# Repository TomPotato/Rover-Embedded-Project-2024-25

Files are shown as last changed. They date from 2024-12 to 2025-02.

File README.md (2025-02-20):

<h1 align="center">The Mars Rover: WALL-E</h1>

<p>With this project we aim to get a better understanding of what skills developing a Mars Rover takes.</p>
<p><i>"How does a Rover really work?","What actions or characteristics define a machine as a Rover?","How can we transmit and receive data from the Rover?"</i></p>
<p>While it would be challenging to build a full functioning Mars Rover in a limited timeframe, understanding how they work and the challenges engineers face, can give us a greater appreciation for the level of innovation and precision that goes into their development.</p>

<h3 align="center">The finished Product</h3>

<p float="left" align="center">
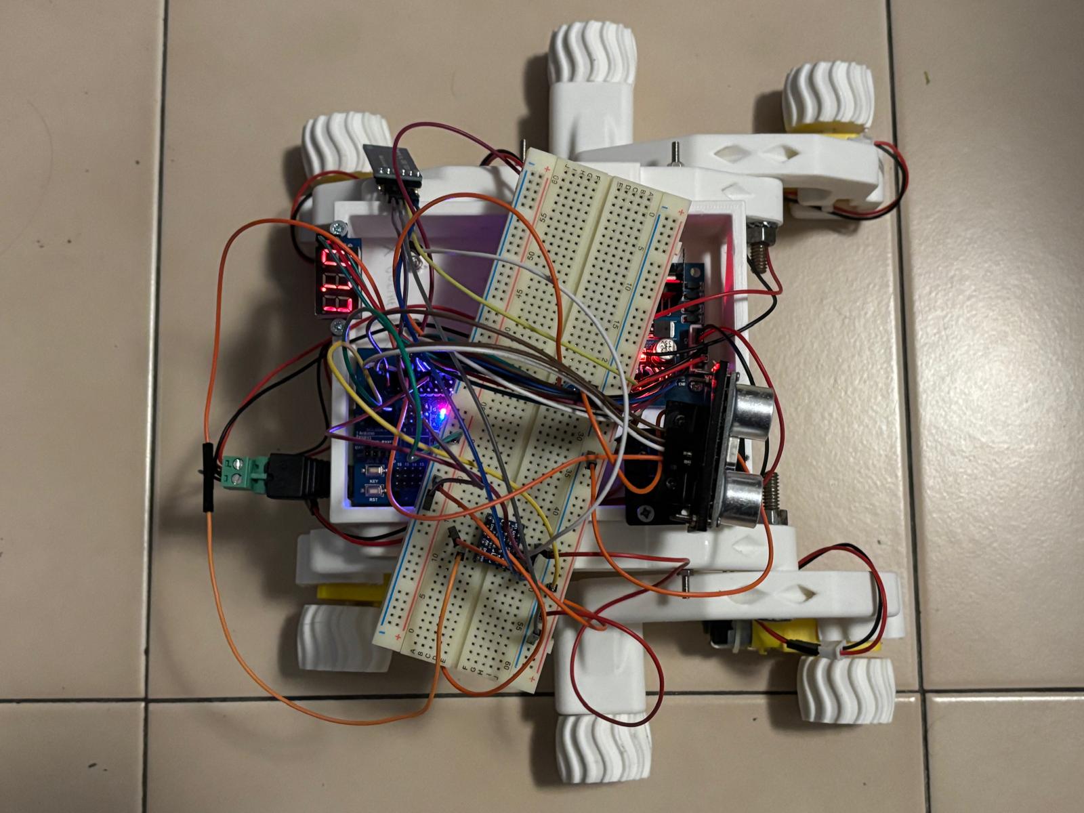
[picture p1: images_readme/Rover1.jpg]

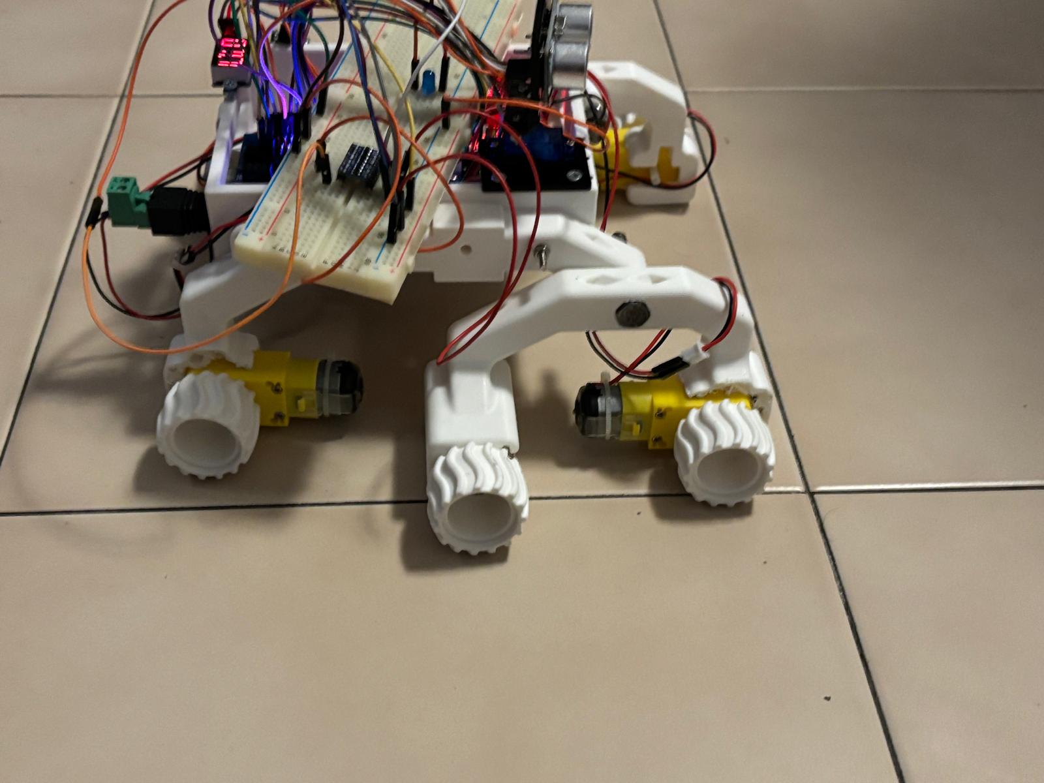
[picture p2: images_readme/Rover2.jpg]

</p>

<br>

<p float="left" align="center">
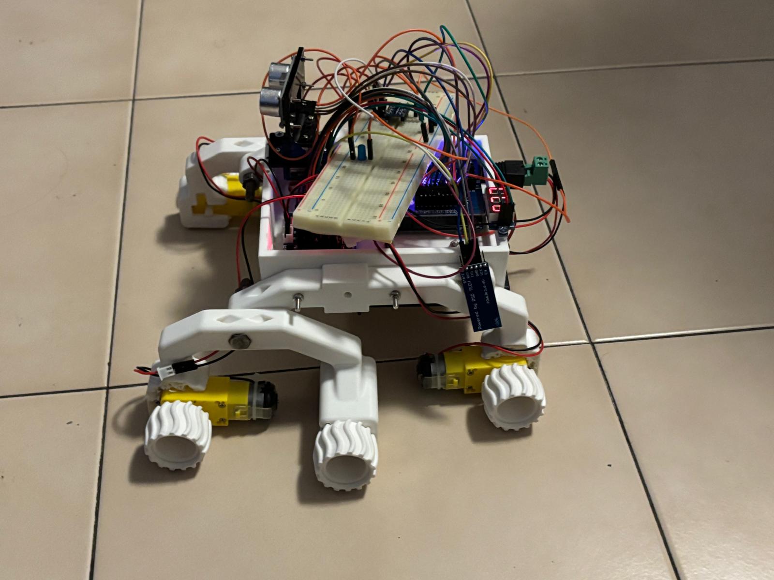
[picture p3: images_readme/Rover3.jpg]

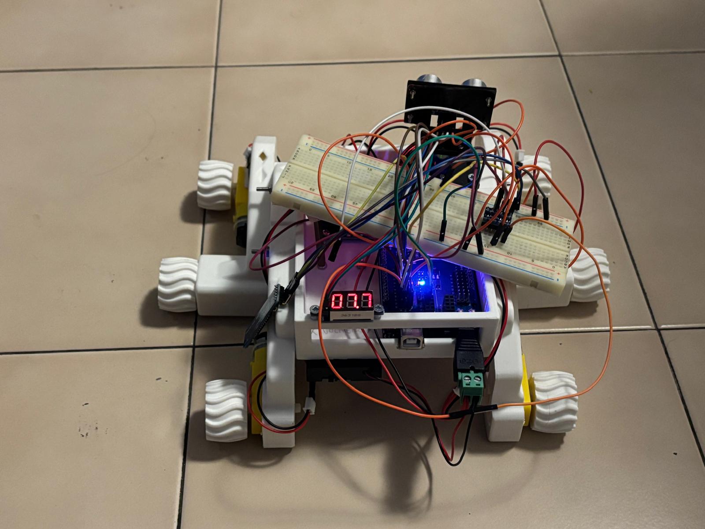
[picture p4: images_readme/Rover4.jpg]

</p>

<h2 align="center">Link to the Youtube video</h2>

<br>
<p>Here you'll find the link to the video of the project: <a href = "https://www.youtube.com/watch?v=d_bhMyztT9k">https://www.youtube.com/watch?v=d_bhMyztT9k</a></p>
<br>

<h2 align="center">Components</h2>

<h3 align="center">Physical Components Used</h3>

<ul>
    <li>a few (a lot) 3d printable components</li>
    <li>4x mini servomotors of 3v outtage</li>
    <li>27x Jumpers Arduino</li>
    <li>1x Micro Servo motor SG90</li>
    <li>1x Arduino compatible Voltmeter</li>
    <li>1x Arduino OSOYOO UNO Board</li>
    <li>1x Arduino ESP8266 Shield for Arduino</li>
    <li>1x Buzzer compatible with Arduino</li>
    <li>1x Module Driver Motors OSOYOO Model X</li>
    <li>1x Bluetooth sensor Arduino compatible HC-05</li>
    <li>1x Ultrasonic sensor HC-SR04</li>
    <li>nx Various screws and knobs to model the Body of the Rover</li>
    <li>1x BatteryPack</li>
        <ul>
        <li>2x Rechargable Batteries of 3.7V, ~3.000 mA</li>
        <li>1x Batteries Charge Station</li>
        </ul>
    <li>1x Texas Instruments MSP432P401R</li>
    <li>1x Texas Instruments BoosterPack MKII</li>
    <li>1x Breadboard</li>
    <li>1x Logic level converter</li>
    <li>1x LED</li>
    <li>1x PC/LAPTOP</li>
</ul>

<h3 align="center">Software Used</h3>

<ul>
    <li>Visual Studio Code</li>
    <li>Arduino IDE</li>
    <li>Energia IDE</li>
    <li>Putty Serial Communication App</li>
    <li>Windows CMD/Powershell</li>
</ul>

<h3 align="center">Programming Languages used</h3>

<ul>
    <li>C/C++</li>
    <li>Python</li>
</ul>

<h3 align="center">Libraries used</h3>

<ul>
    <li>Python library:serial</li>
    <li>Arduino library: SoftwareSerial.h , Servo.h</li>
</ul>

<h2 align="center">Project Layout</h2>

<pre>
<code>
ROVER WALL-E
│
├── README.md
├── LICENSE (MIT defined)
├── rover_exoscheleton               # stl used for the exoskeleton of the rover
├── images_readme                   
│   └──images                        # images used inside the readme
├── images_schematics               
│  └──images                         # schematics of the Arduino jumpers connections in the Rover
├── videos                           # snippets of the pitch video
├── Presentation                     # presentation of the project
└── Our Code
    ├── ArduinoUNO                   # Arduino side code
    │   ├── ComponentsCode           # Components template code with testing before implementation
    │   └── RoverFinalSketch         # Final sketch to be burned into the Rover
    ├── MSP43P401R                   # Texas side code
    └── SideCode                     # Side code to make the BT module connect to the pc 
</code>
</pre>

<h2 align="center">How to Reproduce the Project</h2>

<h3 align="center">Goals</h3>

<ul>
    <li>Sending commands from MSP432 (with attached a BoosterPack) to arduino via bluetooth to control the rover </li>
    <li>Commands that can be Issued:</li>
    <ul>
        <li>F(Forward)</li>
        <li>B(Backward)</li>
        <li>L(Left)</li>
        <li>R(Right)</li>
        <li>P(rovers' led on)</li>
        <li>W(rovers' led off)</li>      
    </ul>
    <li>Sending rovers' led status and ultrasonic data from arduino to the pc/laptop</li>
    <li>The multicolor LED integrated into the BoosterPack operates in accordance with control commands (e.g., LED ON/OFF) transmitted by the Arduino.</li>
</ul>

<h3 align="center">Steps</h3>
<ol>
    <i>After you printed the Rover Components and built its exoscheleton as the image shown below</i>
    <p>
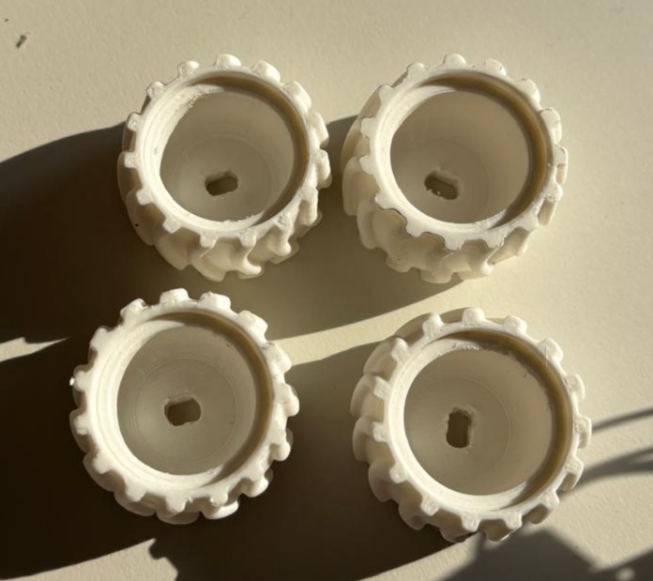
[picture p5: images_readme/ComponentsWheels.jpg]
    
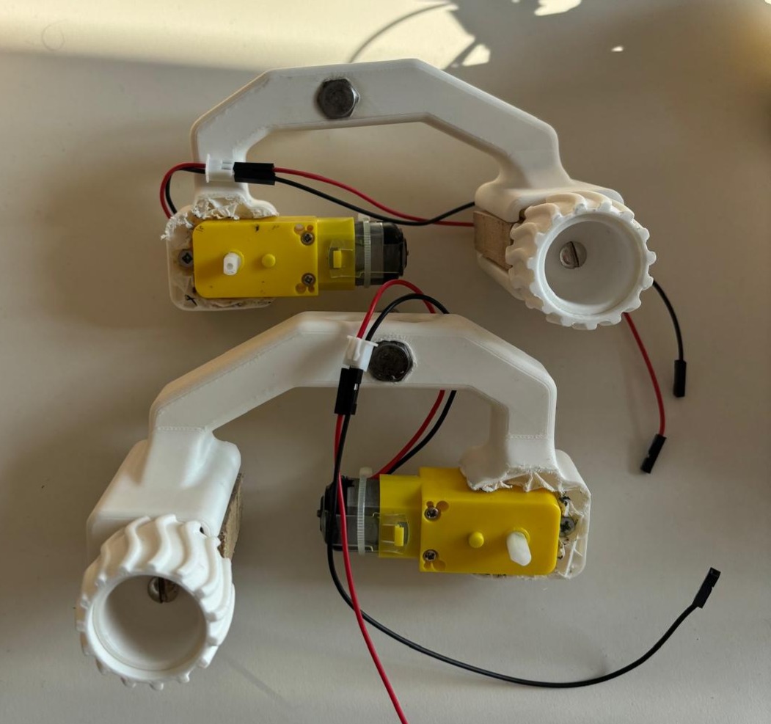
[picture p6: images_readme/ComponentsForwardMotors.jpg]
    
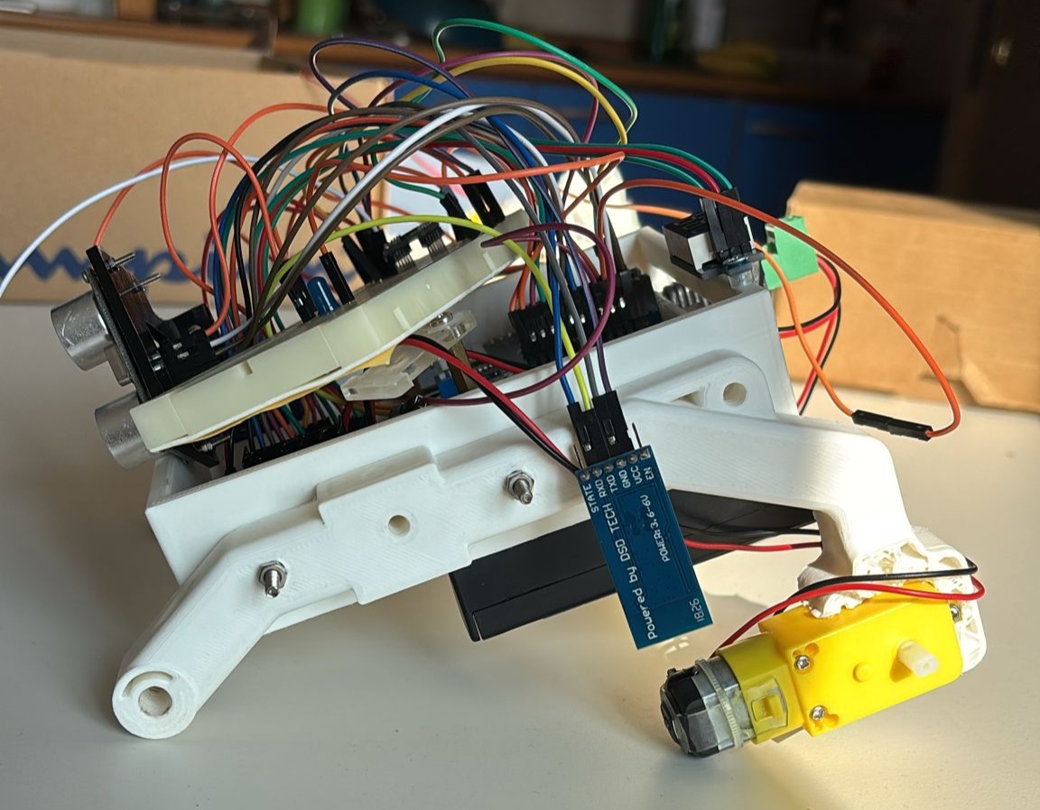
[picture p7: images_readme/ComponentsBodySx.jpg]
    
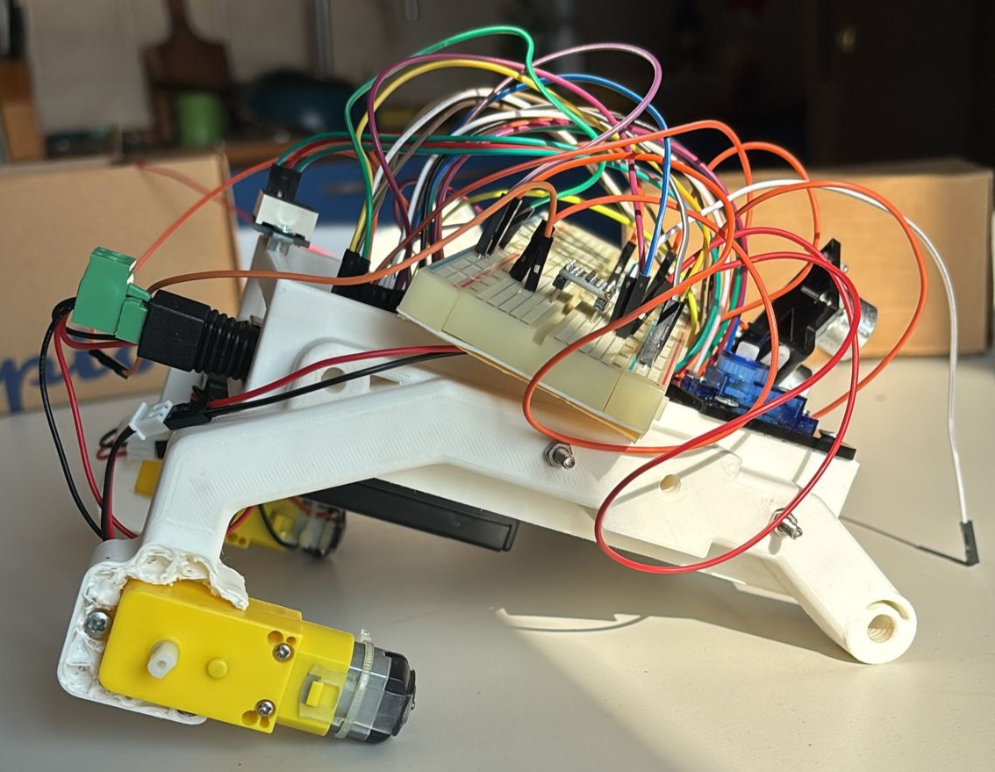
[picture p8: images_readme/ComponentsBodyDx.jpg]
    
    </p>
    <li>Upload the MSP code on MSP432 using <a href="https://energia.nu/">Energia IDE</a></li>
    
    <li>Test whether the commands are sent correctly using serial monitor (Close the serial monitor to free the port after you finished testing)</li> 
    <li>Upload "RoverArduinoFinalSketch.ino" on Arduino Uno using <a href="https://www.arduino.cc/en/software">Arduino IDE</a></li> 
    <i>(check that the baudrate of the Arduino board and BT Module are compatible)</i>
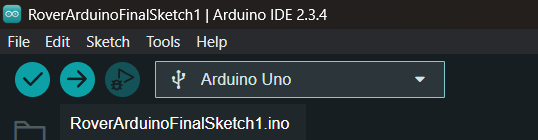
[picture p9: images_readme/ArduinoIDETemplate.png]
    
    <li>Power up the rover</li>
    <li>Enstablish the connection between pc and HC05 using <a href="https://www.putty.org/">PuTTY</a></li>
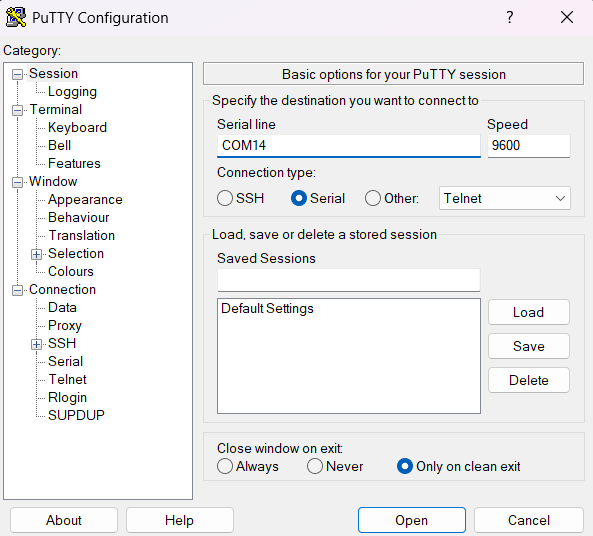
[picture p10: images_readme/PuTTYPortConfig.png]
    
        <ol>
            <li>select the connection type as serial</li>
            <li>select the COM port that identifies the BT connection on your pc</li>
            <i>You can use the sessions Default Settings as the code does not save specifics</i>
        </ol>
    <li>Run the python script on your pc using CMD quickly after closing PuTTY </li>
    <li>The Rover will commence any action only after he is connected to the "Master" controller and has commence in receiving data</li>
    <i>If everything went well, the rover should have started the "Ambiental Scan" by sending the Scan start/end message and the eventual obstacles position</i>
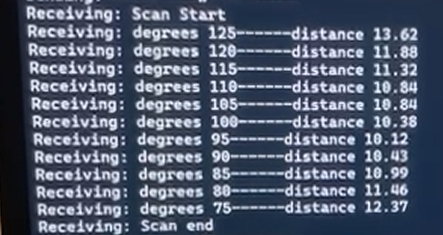
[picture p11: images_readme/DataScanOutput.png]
    
    <li>Use the two buttons integrated into the BoosterPack to activate and deactivate the rover's LED to test the communication. Once the LED ON/OFF message is received from the Arduino, the BoosterPack's multicolor LED should turn on/off respectively.</li>
    <li>Use the joystick to control the rovers' movement, and the two buttons integrated into the BoosterPack to activate and deactivate the rover's LED.</li>
    <li>If you want to Re-Scan the environment, the Rover has to stay still for ~5 seconds (receive 10 S signals)</li>
</ol>

<h3 align="center">Contributors</h3>

<p><i>Agosti Tommaso, Nodari Francesco, Wu Alessio, Wu Davide</i></p>
<br>

<h6>
<i>
<ul>
    <li>RICORDA</li>
    <li>non funziona se non cade una sigaretta elettronica almeno 15 volte</li>
    <li>RX e TX non sono posizionati correttamente, scambiali... oppure no?</li>
    <li>hc-05 non funziona coi 5V!!! breadboard joins the chat</li>
    <li>Pin 0 e 1 non sono da utilizzare o ti esplode il buffer!!! (servono per il debug e il monitor seriale)</li>
</ul>
</i>
</h6>

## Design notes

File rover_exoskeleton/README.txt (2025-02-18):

All the 3d models that we used in order to print and develope the rover, made with the Model of the Curiosity Mars Rover

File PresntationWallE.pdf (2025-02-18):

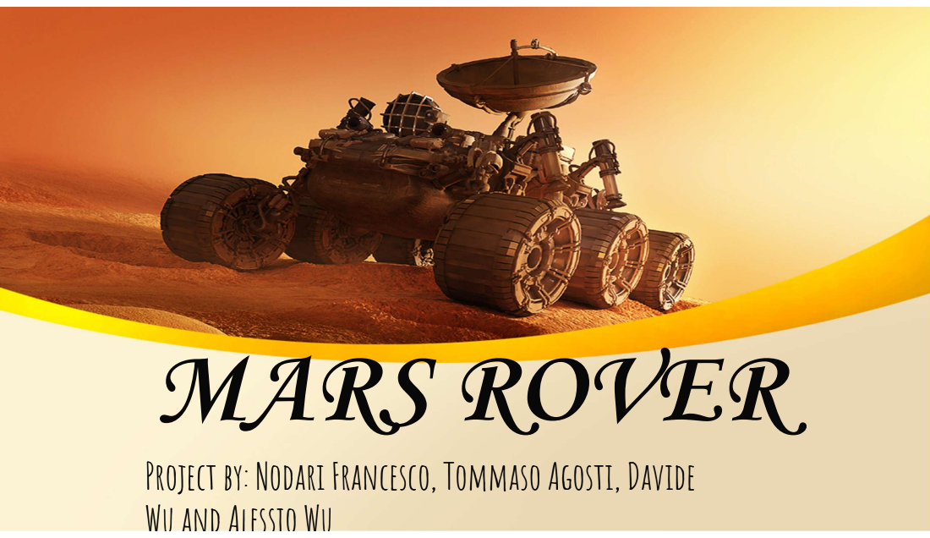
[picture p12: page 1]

Project by: Nodari Francesco, Tommaso Agosti, Davide
Wu and Alessio Wu

## System basic workflow

The hole robot was produced using a 3D printer.
Using the MSP432 boosterpack potentiometer we are able to control the robot movement, as a master; the informations are passed to the computer, via cable, and then to the hc05 via bluetooth.
The Arduino Uno, the slave, which will move accordingly to the commands.
An ultrasonic sensor, is mounted to detect the object near the rover and sends an interrupt if it is too close.

## Project system flow

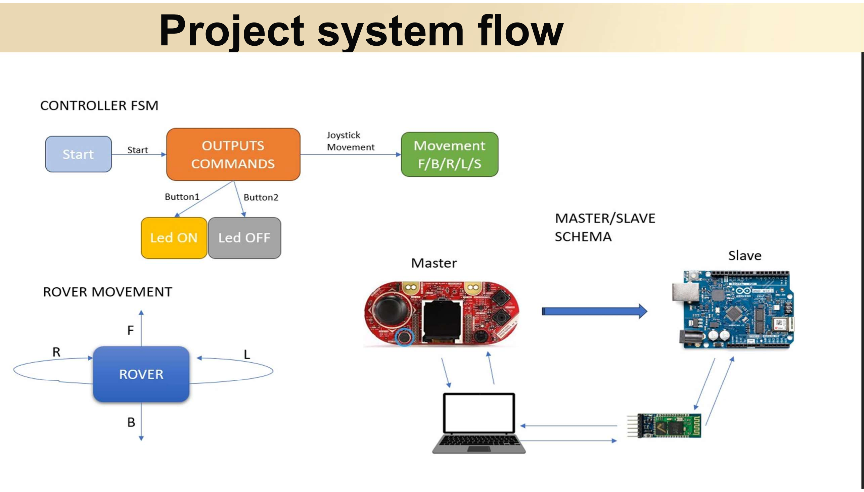
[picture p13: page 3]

## Bluetooth connection summary

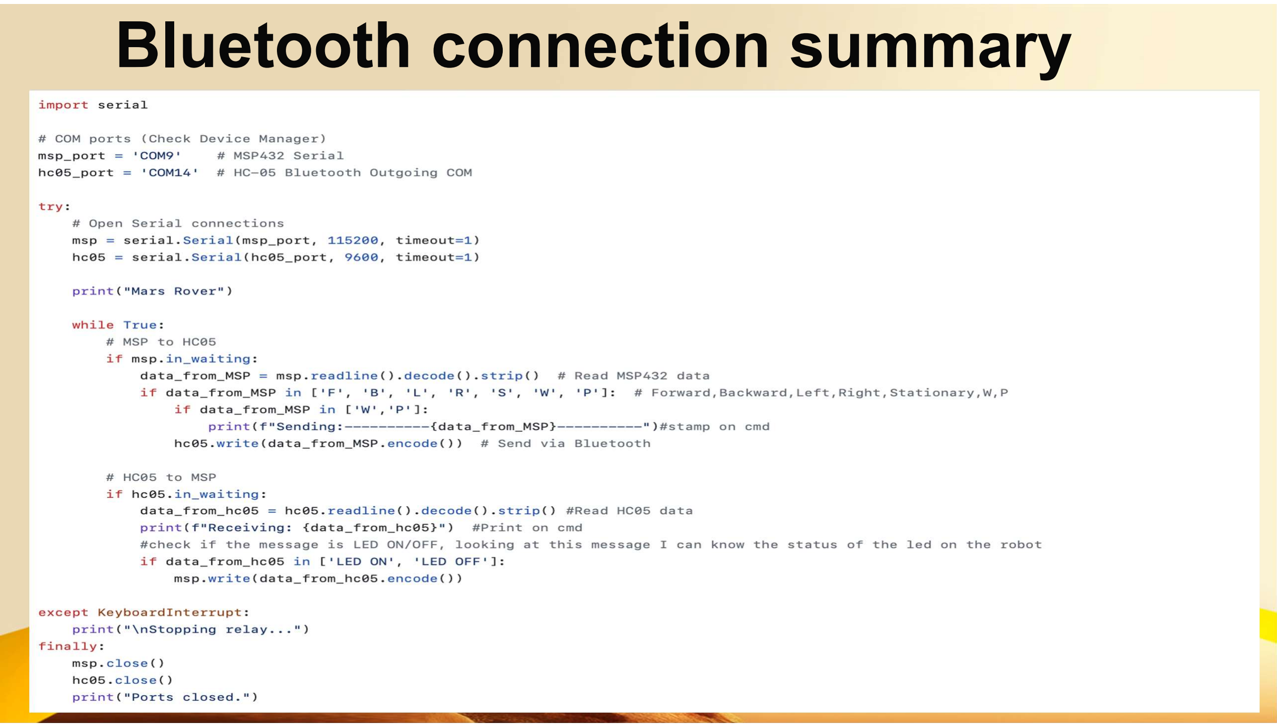
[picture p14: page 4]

## Part of Rover’s movement

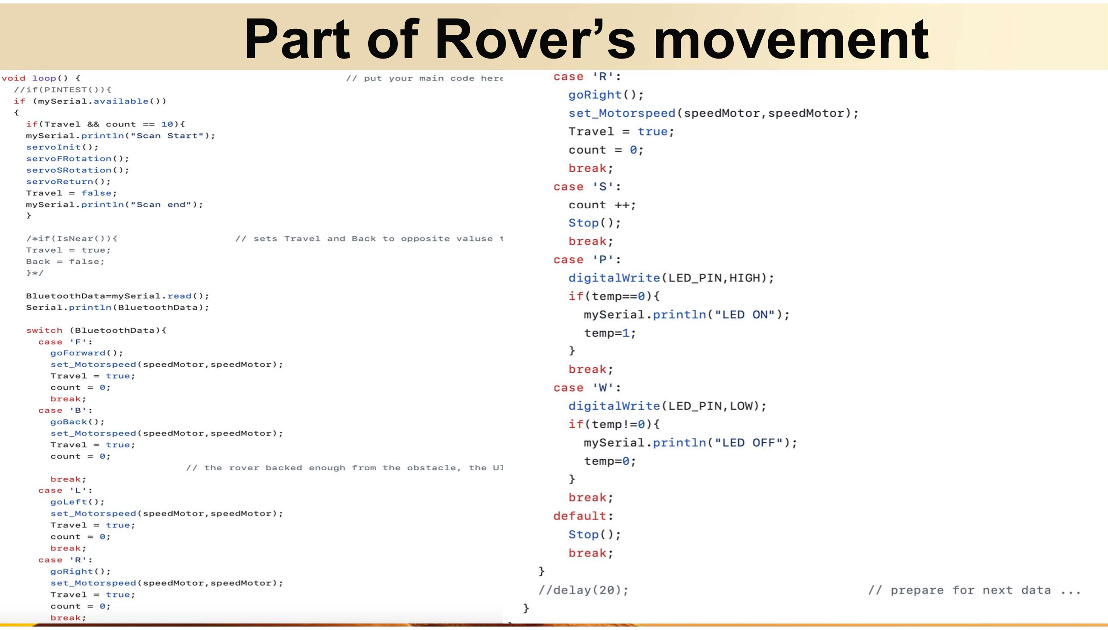
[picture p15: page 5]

### Part of Ultrasonic Sensor

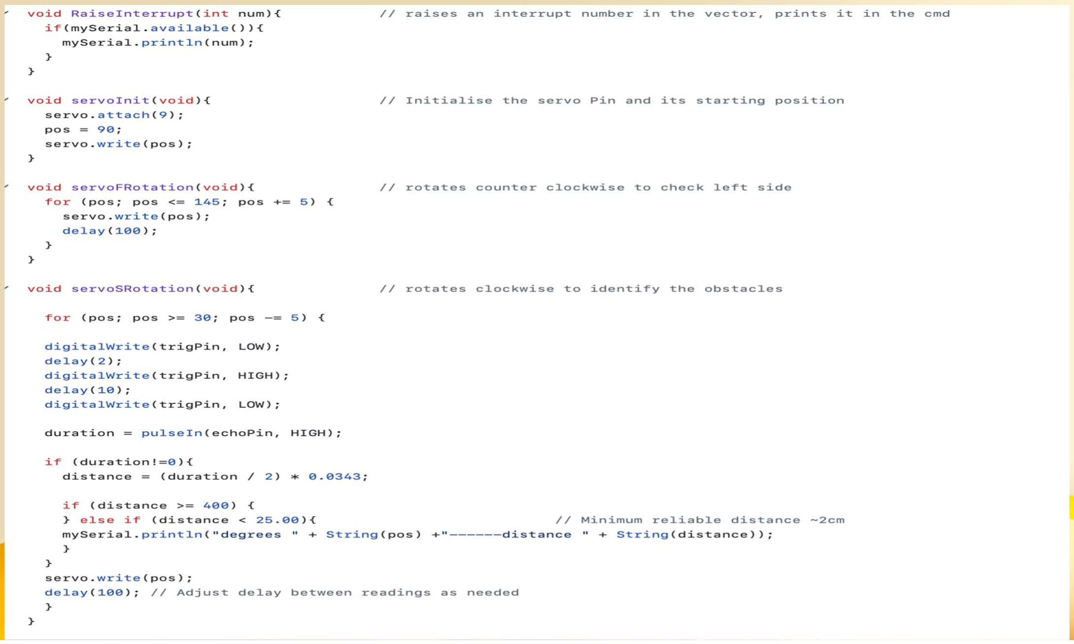
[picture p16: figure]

## Message Passing

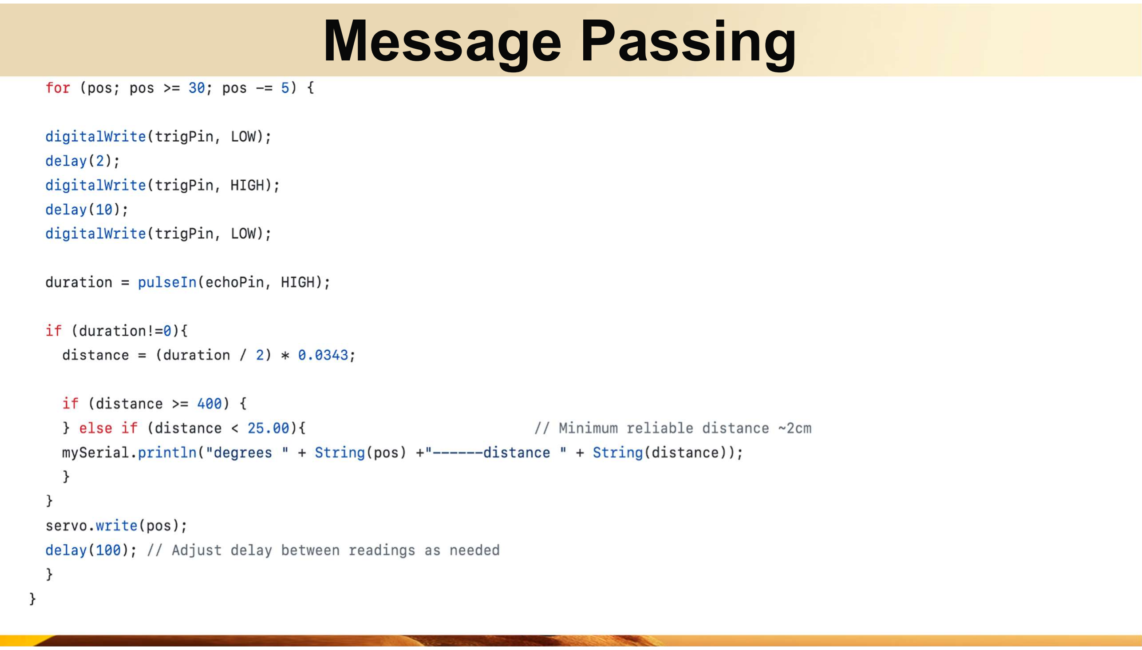
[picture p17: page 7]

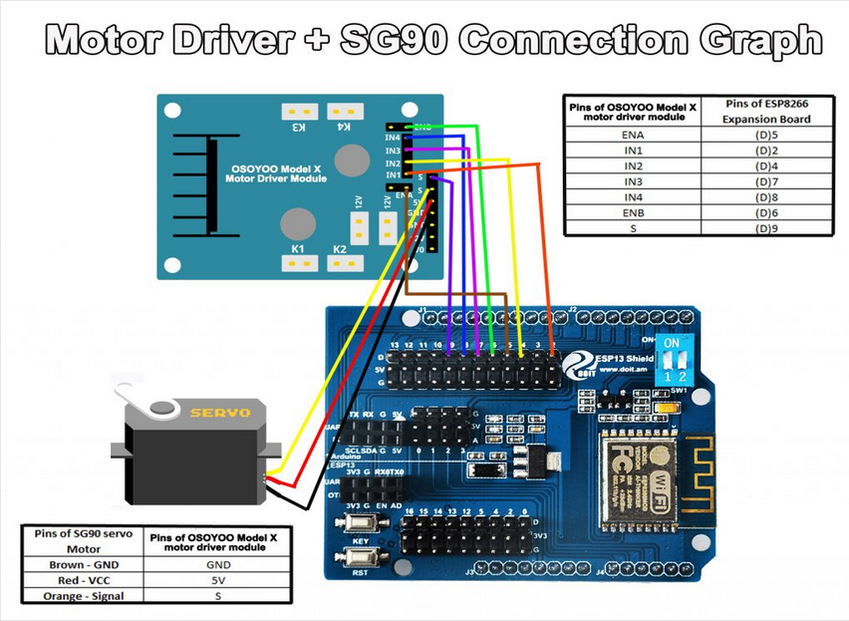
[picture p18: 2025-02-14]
images_schematics/MDriverServoConnectionPath.png

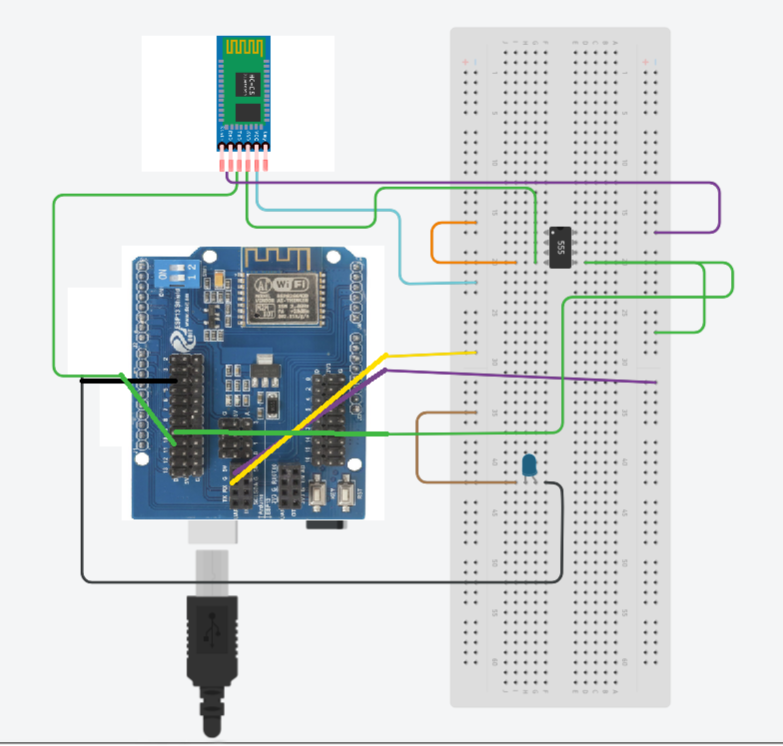
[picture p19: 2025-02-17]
images_schematics/BluetoothLEDModulePath.PNG

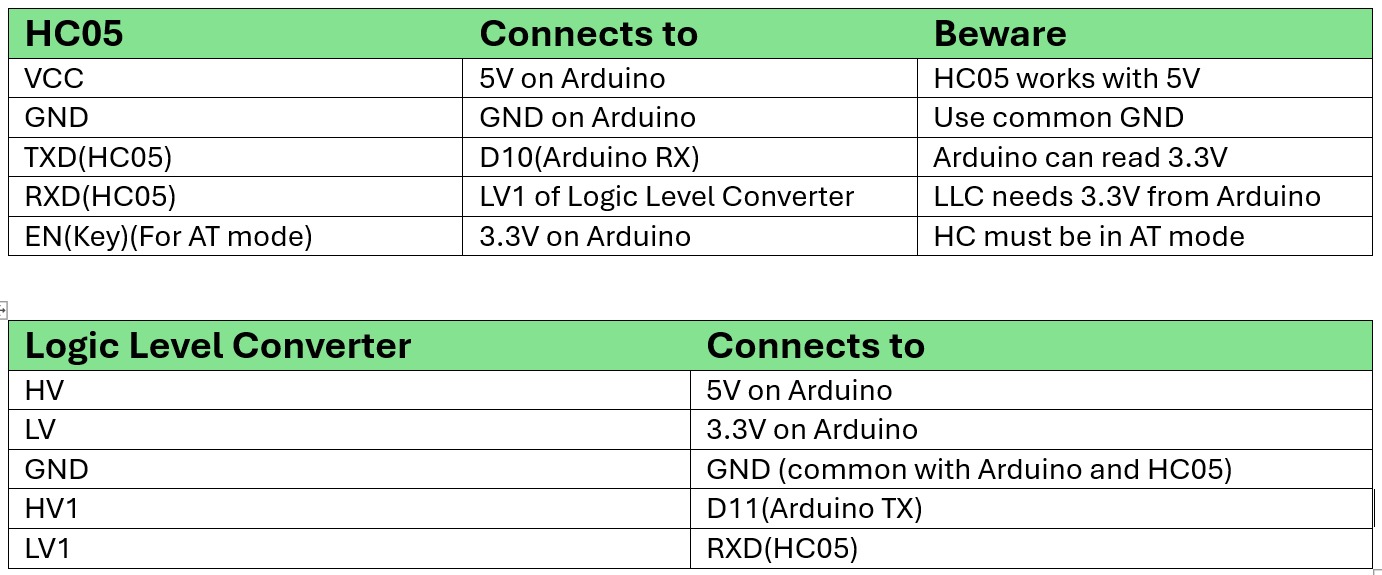
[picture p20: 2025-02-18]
images_schematics/BTModuleConnectionPathSchema.jpg

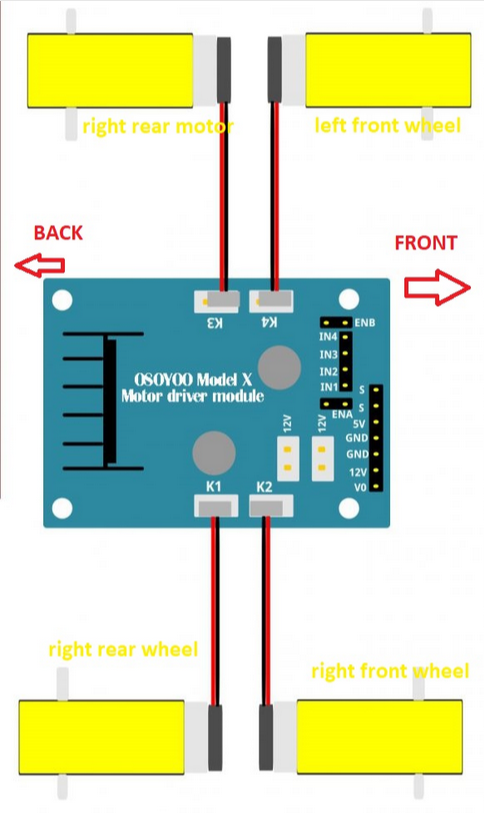
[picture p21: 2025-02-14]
images_schematics/Motors schema.png

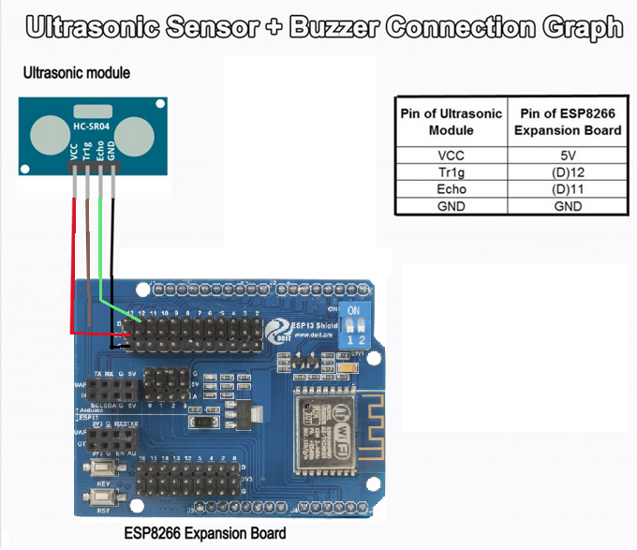
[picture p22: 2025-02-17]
images_schematics/UltrasonicModulepath.png

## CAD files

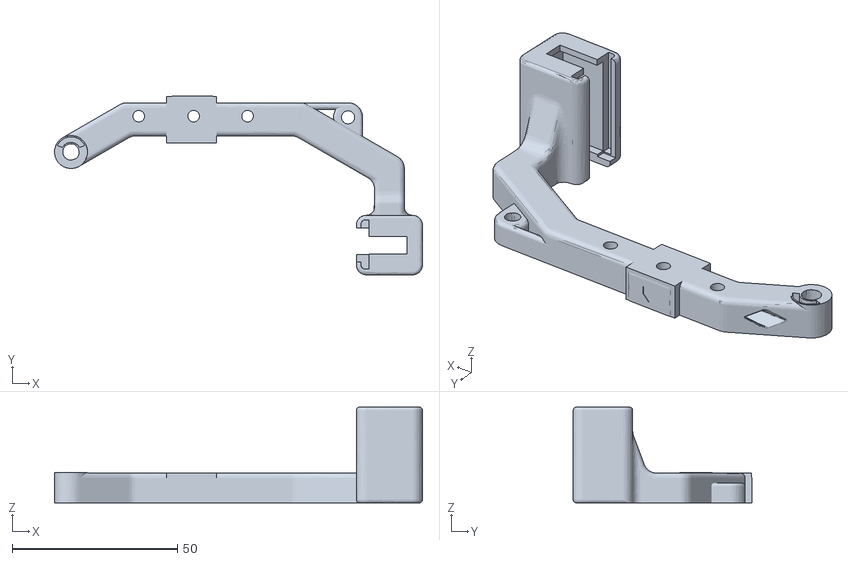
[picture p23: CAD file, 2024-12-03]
rover_exoskeleton/main_axl_1.stl
111.2 x 54.0 x 29.0

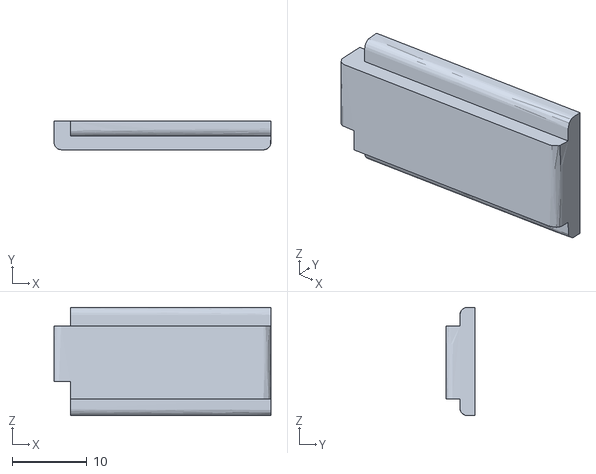
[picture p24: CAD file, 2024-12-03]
rover_exoskeleton/bracket_right.stl
29.0 x 3.83 x 14.5

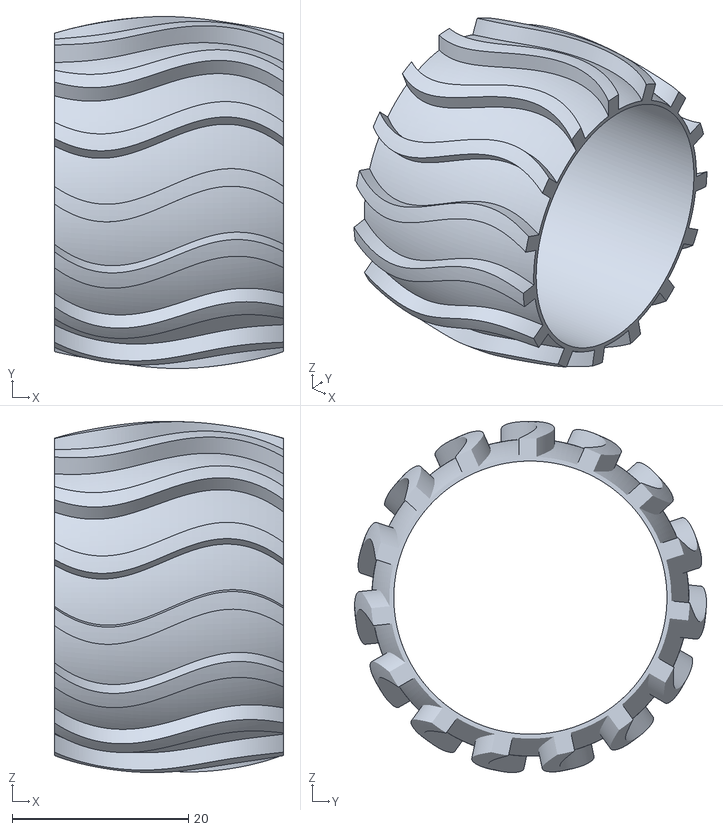
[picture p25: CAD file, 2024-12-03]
rover_exoskeleton/tire.stl
26.0 x 40.0 x 39.9

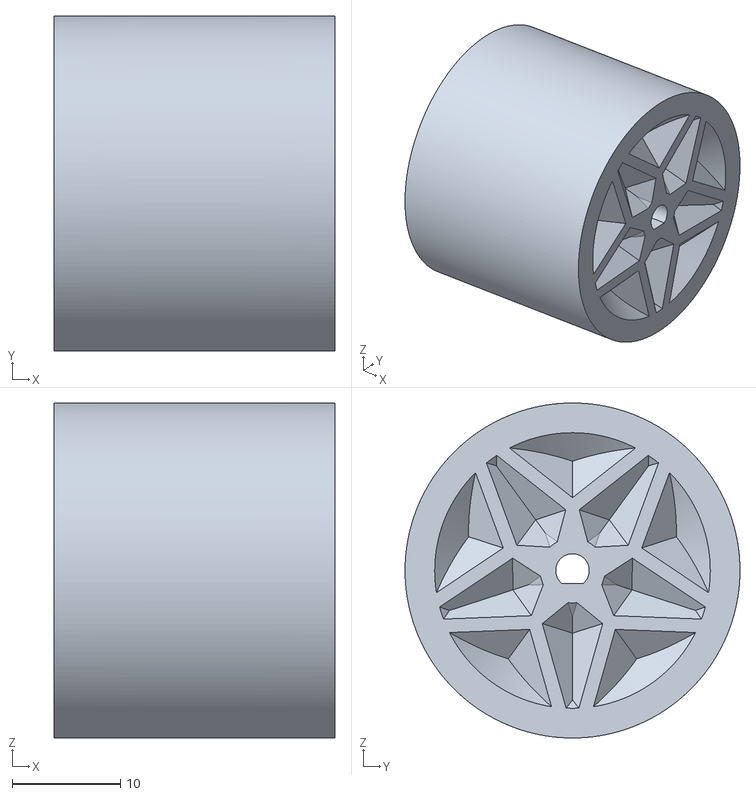
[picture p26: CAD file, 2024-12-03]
rover_exoskeleton/wheel.stl
26.0 x 31.0 x 31.0

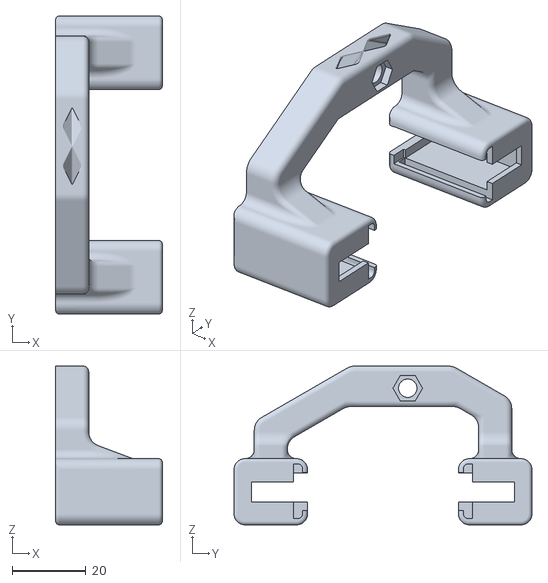
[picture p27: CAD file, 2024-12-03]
rover_exoskeleton/left_v1.stl
29.0 x 81.0 x 43.1

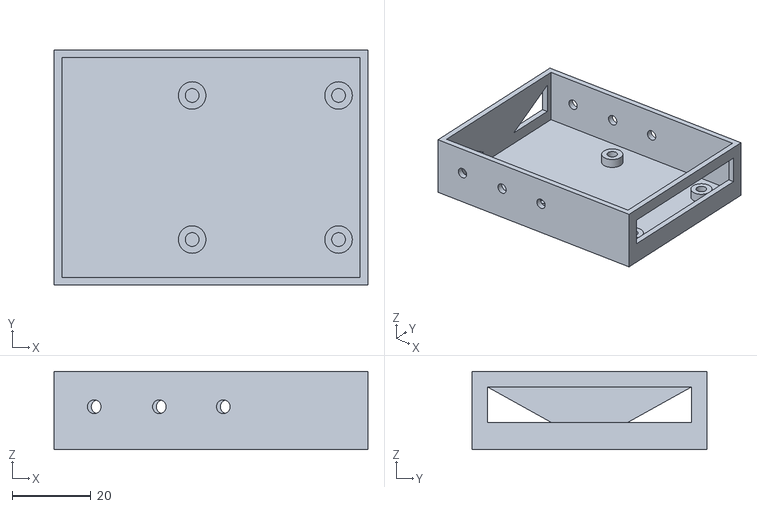
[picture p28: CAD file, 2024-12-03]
rover_exoskeleton/body.stl
80.0 x 60.0 x 20.0

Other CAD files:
rover_exoskeleton/main_axl_2.stl
rover_exoskeleton/right_v1.stl
rover_exoskeleton/bracket_left.stl

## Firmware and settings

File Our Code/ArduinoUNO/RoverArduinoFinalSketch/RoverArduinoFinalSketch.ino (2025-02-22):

#include "SoftwareSerial.h"                   // import the serial library for the BLE module communication
#include "Servo.h"                            // Servo motor library

int i = 0;
int temp = 0;

int count = 10;           // numbers of command S received 
                          //it is used to decide how much time the Rover can stay still before it initialaizes a scan

bool Travel = true;       // check to see if the rover traveled more than 0 cm

int pinTotal = 19;      // defines the total of the pins that are used in the Arduino

#define dir1PinL  7    //Motor direction Forward left side motors
#define dir2PinL  8    //Motor direction Backwards left side motors
#define speedPinL 6    // Needs to be a PWM pin to be able to control motor speed
#define dir1PinR  2    //Motor direction Forward right side motors
#define dir2PinR  4   //Motor direction Backwards right side motors
#define speedPinR 5    // Needs to be a PWM pin to be able to control motor speed
#define speedMotor 200  // sets the "speed" of the motor, from 0, completeley still, to 255, max outtage

#define LED_PIN 3       // led accension pins

#define echoPin 13
#define trigPin 12
float duration, distance;  // used to obtain the distance between the ultrasonic component and the obstacle

Servo servo;              // define the name of the servo motor 
int val;                  // rotation angle
int pos=90;               // start position of the servo

/*typedef struct{           // used to define the position in the space of the obstacles and the Rover
  int x;
  int y;
} Obstacle;

Obstacle obstacle[150];   // array of obstacles
Obstacle Me;              // Rover Itself*/
int angle = 90;           // angle from which the rover starts

SoftwareSerial mySerial(10, 11);        // RX (Read Pin), TX (Tell Pin)
int BluetoothData;                      // the data given from Computer

void setup(){                            // setup code, initialaizes the pins etcetera
  servo.attach(9);     //pin 9 for servo
  
  pinMode(2,OUTPUT);   //left motors  forward
  pinMode(4,OUTPUT);   //left motors reverse
  pinMode(7,OUTPUT);   //right  motors forward
  pinMode(8,OUTPUT);   //right motors reverse

  pinMode(speedPinL, OUTPUT);
  pinMode(speedPinR, OUTPUT);
  
  Serial.begin(9600);

  pinMode(trigPin, OUTPUT);
  pinMode(echoPin, INPUT);
  
  mySerial.begin(9600);  //serial bluetooth module initializing
}

/*bool PINTEST(void){                     // tests if the pins are connected to something or not, might be implementable in the near future
  do{
    if(digitalRead(pinTotal)==0){
      switch(pinTotal){
        case 0:
          RaiseInterrupt(2);
          Serial.println("Error Pin Rx detached");
          return false;
          break;
        case 1:
          RaiseInterrupt(2);
          Serial.println("Error Pin Tx detached");
          return false;
          break;
        case 2:
          RaiseInterrupt(2);
          Serial.println("Error Pin RMotorB detached");
          return false;
          break;
        case 3:
          RaiseInterrupt(2);
          Serial.println("Error Pin RMotorB detached");
          return false;
          break;
        case 4:
          RaiseInterrupt(2);
          Serial.println("Error Pin RMotorF detached");
          return false;
          break;
        case 5:
          RaiseInterrupt(2);
          Serial.println("Error Pin SpeedRMotor detached");
          return false;
          break;
        case 6:
          RaiseInterrupt(2);
          Serial.println("Error Pin SpeedLMotor detached");
          return false;
          break;
        case 7:
          RaiseInterrupt(2);
          Serial.println("Error Pin LMotorF detached");
          return false;
          break;
        case 8:
          RaiseInterrupt(2);
          Serial.println("Error Pin LMotorB detached");
          return false;
          break;
        case 9:
          RaiseInterrupt(2);
          Serial.println("Error Pin ServoMotor detached");
          return false;
          break;
        case 11:
          RaiseInterrupt(2);
          Serial.println("Error Pin LED detached");
          return false;
          break;
        case 12:
          RaiseInterrupt(2);
          Serial.println("Error Pin TRIG detached");
          return false;
          break;
        case 13:
          RaiseInterrupt(2);
          Serial.println("Error Pin ECHO detached");
          return false;
          break;
        default:
          RaiseInterrupt(3);
          Serial.println("No CLUE found");
          break;
      }
    }
    pinTotal--;
  }while(pinTotal>=0);
}*/

void RaiseInterrupt(int num){           // raises an interrupt number in the vector, prints it in the cmd
  if(mySerial.available()){
    mySerial.println(num);
  }
}

void servoInit(void){                   // Initialise the servo Pin and its starting position
  servo.attach(9);  
  pos = 90;
  servo.write(pos);
}

void servoFRotation(void){              // rotates counter clockwise to check left side
  for (pos; pos <= 145; pos += 5) {         
    servo.write(pos);
    delay(100);
  }
}

void servoSRotation(void){              // rotates clockwise to identify the obstacles
  
  for (pos; pos >= 30; pos -= 5) {       

  digitalWrite(trigPin, LOW);
  delay(2);
  digitalWrite(trigPin, HIGH);
  delay(10);
  digitalWrite(trigPin, LOW);

  duration = pulseIn(echoPin, HIGH);

  if (duration!=0){
    distance = (duration / 2) * 0.0343;

    if (distance < 25.00){                           // Minimum reliable distance ~2cm
    mySerial.println("degrees " + String(pos) +"------distance " + String(distance));
    }
  }
  servo.write(pos);
  delay(100); // Adjust delay between readings as needed
  }
}


void servoReturn(void){                 // returns the servo in default position (92) and detaches it
  if(pos!=9){
    for (pos; pos <= 90; pos += 5) {
      servo.write(pos);
      delay(100);
    }
    servo.detach();
  }
}


/*bool IsNear(void){                      // defines if the Rover is near an Obstacle 
  int j = i;
  do{
    if( Me.x == (obstacle[j].x - 5) || Me.y == (obstacle[j].y - 5) ){
      mySerial.println("IS NEAR");
      RaiseInterrupt(1);
      return true;
    }
    else{
      return false;
    }
    j--;
  }while(j!=0);
}*/

void goForward(void){                   // move  forward(all motors rotate in forward direction)
  digitalWrite(dir1PinL, HIGH);
  digitalWrite(dir2PinL,LOW);
  digitalWrite(dir1PinR,HIGH);
  digitalWrite(dir2PinR,LOW);
  /*Me.x += 1*sin(angle);                 // updates the position of the Rover in the space
  Me.y += 1*cos(angle);*/
}
void goRight(void){                  //turn left (right side motors rotate in forward direction, left  side motors rotate in reverse)
  digitalWrite(dir1PinL,HIGH);
  digitalWrite(dir2PinL,LOW);
  digitalWrite(dir1PinR,LOW);
  digitalWrite(dir2PinR,HIGH);
  /*if(angle != 360){                   // updates the rotation angle the rover is, for future implementeations
  angle += 5;
  } else{
    angle = 0;
  }*/
}
void goLeft(void){                 //turn right (left side motors rotate in forward direction,  right side motors rotate in reverse)
  digitalWrite(dir1PinL,LOW);
  digitalWrite(dir2PinL,HIGH);
  digitalWrite(dir1PinR,HIGH);
  digitalWrite(dir2PinR,LOW);
  /*if(angle != 0){                 // updates the rotation angle the rover is
  angle -= 5;
  } else{
    angle = 360;
  }*/
}
void goBack(void){                      // move reverse (all  motors rotate in reverse direction)
  digitalWrite(dir1PinL, LOW);
  digitalWrite(dir2PinL,HIGH);
  digitalWrite(dir1PinR,LOW);
  digitalWrite(dir2PinR,HIGH);
  /*Me.x -= 1*sin(angle);               // updates the position of the Rover in the space to implement when sonar
  Me.y -= 1*cos(angle);*/
}
void Stop(void){                        // stops all motors
  digitalWrite(dir1PinL,LOW);
  digitalWrite(dir2PinL,LOW);
  digitalWrite(dir1PinR,LOW);
  digitalWrite(dir2PinR,LOW);
}
void set_Motorspeed(int speed_L,int speed_R){     // sets the motor speed of the Motors
  analogWrite(speedPinL,speed_L); 
  analogWrite(speedPinR,speed_R);   
}

void loop() {                                           // put your main code here, to run repeatedly:
  
  if (mySerial.available())
  {
    if(Travel && count == 10){// count indicates how
    mySerial.println("Scan Start");
    servoInit();
    servoFRotation();
    servoSRotation();
    servoReturn();
    Travel = false;
    mySerial.println("Scan end");
    }

    /*if(IsNear()){                   // sets Travel and Back to opposite valuse to stop the Rover to implement when sonar
    Travel = true;
    Back = false;
    }*/

    BluetoothData=mySerial.read();
    Serial.println(BluetoothData);

    switch (BluetoothData){
      case 'F':
        goForward();
        set_Motorspeed(speedMotor,speedMotor);
        Travel = true;
        count = 0;
        break;
      case 'B':
        goBack();
        set_Motorspeed(speedMotor,speedMotor);
        Travel = true;
        count = 0;
                              // the rover backed enough from the obstacle, the Ultrasonic sensor restarts, new series of obstacles, to implement when Sonar
        break;
      case 'L':
        goLeft();
        set_Motorspeed(speedMotor,speedMotor);
        Travel = true;
        count = 0;
        break;
      case 'R':
        goRight();
        set_Motorspeed(speedMotor,speedMotor);
        Travel = true;
        count = 0;
        break;
      case 'S':
        count ++;
        Stop();
        break;
      case 'P':
        digitalWrite(LED_PIN,HIGH);
        if(temp==0){
          mySerial.println("LED ON");
          temp=1;
        }
        break;
      case 'W':
        digitalWrite(LED_PIN,LOW);
        if(temp!=0){
          mySerial.println("LED OFF");
          temp=0;
        }
        break;
      default:
        Stop();
        break;
    } 
    //delay(20);                               // prepare for next data ...
  }
}

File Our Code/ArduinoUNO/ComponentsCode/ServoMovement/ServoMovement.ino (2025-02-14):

#include "Servo.h"
Servo servo;              // define the name of the servo motor
int val;                  // rotation angle
int pos=92;               // start position of the servo

void setup()
{
  Serial.begin(9600);
  servo.attach(9);        //servo pin
}

void servoAtt(void){
  servo.attach(9);
}

void servoFRotation(void){
    for (pos; pos <= 170; pos += 1) {         // rotate counterclockwise to check
    servo.write(pos);
    delay(20);
  }
}

void servoSRotation(void){
  for (pos; pos >= 20; pos -= 1) {          // rotate clockwise to other check
    servo.write(pos);
    delay(20);
  }
}

void servoReturn(void){
  if(pos!=92){
    for (pos; pos <= 92; pos += 1) {        // returns in default position
      servo.write(pos);
      delay(20);
    }
  }
}

void loop()
{
  servoAtt();
  servoFRotation();
  servoSRotation();
  servoReturn();
  delay(500);
  servo.detach();                           // stops the movement of the servo
}

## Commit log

2025-02-14 Motors ans Servo changes to Black Box
2025-02-16 Aggiunto idee iniziali del vettore di interrupt, funzioni per gestirlo, etc
2025-02-17 Modified Arduino Code
2025-02-17 Modified Arduino final code
2025-02-17 Added the PIN test function to stop/make the Rover start
2025-02-17 Added UltrasonicModuleConnectionPath
2025-02-18 Added SChematics BTModule
2025-02-18 Stl folder cleaned
    [Pivot_stopper.stl]
